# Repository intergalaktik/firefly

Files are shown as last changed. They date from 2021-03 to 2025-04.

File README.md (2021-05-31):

# Firefly

Board is designed to run custom made panels designed by Novena.

Designed to drive LED strip WS28121/WS28121

Depending on components and jumpers board can be sender or receiver. 

RJ45 connector is used as it is cheap.

UTP Cables are cheap and easily available.

Sender board is connected over USB to computer.

Currently sender board is just use as USB > RS485 pass

On receiver board switches are used to set panel ID

On computer software we can assign each LED to one or more groups and change group color with just one message.

Currently this board is using custom designed RS485 protocol.

Simple example of using LED group

https://www.youtube.com/watch?v=NDzNr1LaLNI

Example with more features implemented

https://youtu.be/98tDE7uqz9s

Testing blender render 

https://www.youtube.com/watch?v=SnCAtjjVjGQ

Parts of schematics are from:

https://github.com/TimGremalm/LightBoxNano

PCBart blender style

https://github.com/pcbarts/stylized-blender-setup

40 pcs. batch for museum installation

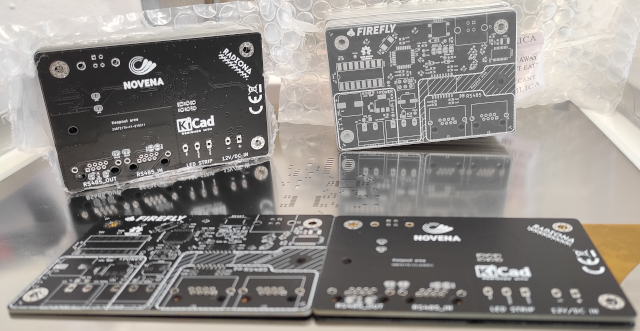
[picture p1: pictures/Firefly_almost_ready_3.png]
Stencil


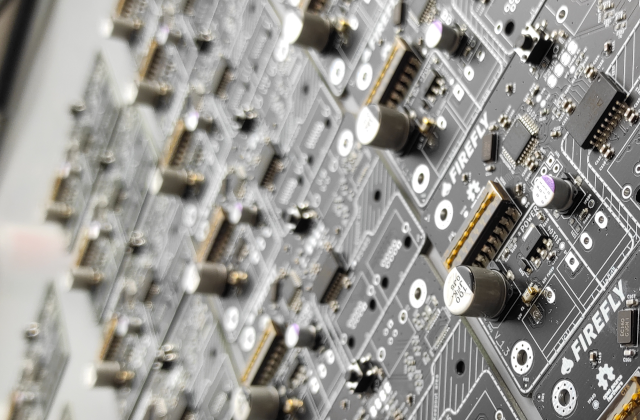
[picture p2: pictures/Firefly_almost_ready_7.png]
Half


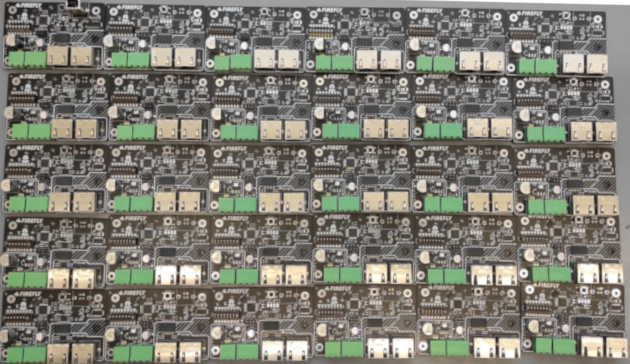
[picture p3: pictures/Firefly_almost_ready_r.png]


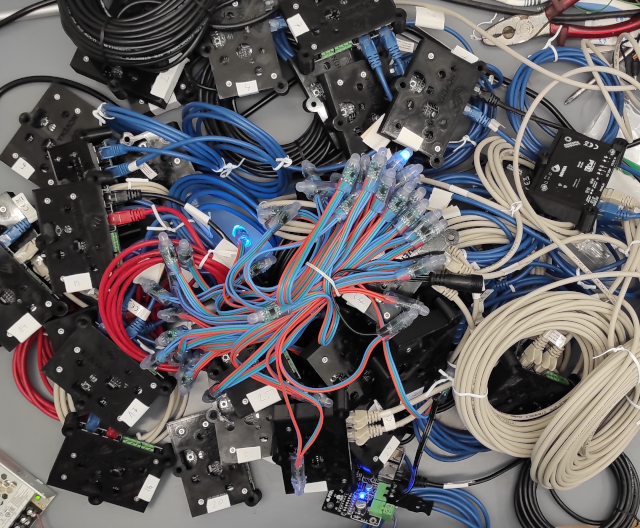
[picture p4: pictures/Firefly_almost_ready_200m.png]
Done


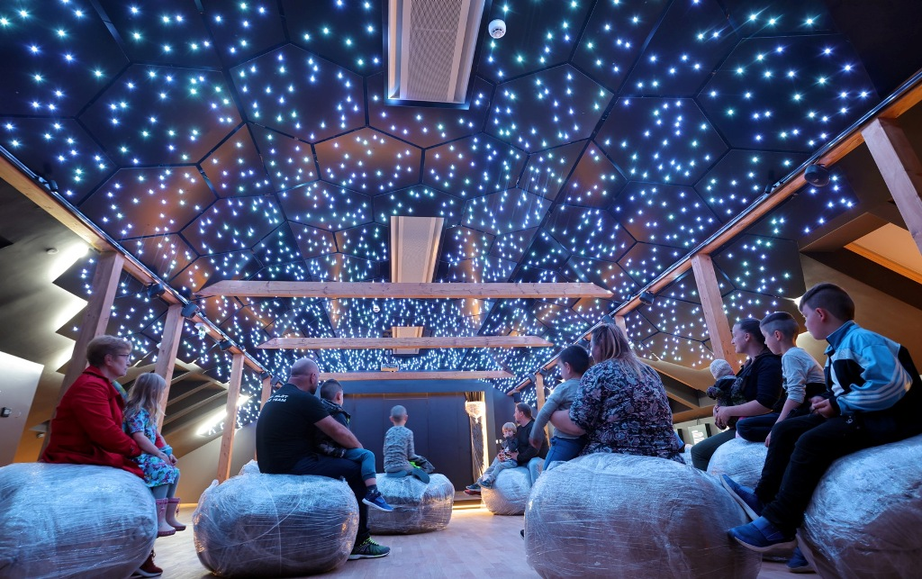
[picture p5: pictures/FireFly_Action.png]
Action


DMX test

https://www.youtube.com/watch?v=Ih8ujr5BlC8

https://www.youtube.com/watch?v=qBxfGmqJY24

https://www.youtube.com/watch?v=aGFyOSpUzw4

https://www.youtube.com/watch?v=s4EHGpA8z-Q&t=11s

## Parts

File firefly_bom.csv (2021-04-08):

References | Qty | Description | Manufacturer | MPN | Manufacturer | MPN | Manufacturer | MPN | Digikey | Mouser | RS | Newark | Farnell
Cvin1 | 1 | 100uF 50V 27m? CP_Elec_10x10 | Cornell Dubilier | AFK107M63G24T-F |  |  |  |  | 338-2146-6-ND | 5985AFK63V100F |  |  | 2131903
C101 | 1 | 100uF/16V CP_Elec_6.3x5.3 | Panasonic | 16SVPT100M |  |  |  |  | 10-16SVPT100MDKR-ND | 66716SVPT100M | 2018078 |  | 3266925
C102, C103, C108, C113, C114, C117, C118, C119, C120, C121, C122, C123, C124, C201, C205, C206 | 16 | 100n C_0603_1608Metric | Würth Elektronik | 885012206046 |  |  |  |  | 732-7965-6-ND | 710885012206046 | 8392811 |  | 2495170
C104, C105, C111, C112, C115, C116 | 6 | 10n C_0603_1608Metric | Würth Elektronik | 885012206040 |  |  |  |  | 732-7959-6-ND | 710885012206040 | 8392798 |  | 2534021
C106, C107 | 2 | 22pF C_0603_1608Metric | Würth Elektronik | 885012006019 |  |  |  |  | 732-7762-6-ND | 710885012006019 | 1813967 |  | 2533830
C109, C110 | 2 | 1uF C_0603_1608Metric | KEMET | C0603C105K8PAC |  |  |  |  |  | 80C0603C105K8PAC
C203, C204 | 2 | 47pF C_0603_1608Metric | Würth Elektronik | 885012006021 |  |  |  |  | 732-7764-1-ND | 710885012006021 | 1813913 |  | 2812096
C202 | 1 | 4.7uF C_1210_3225Metric | Würth Elektronik | 885012107013 |  |  |  |  | 732-7623-1-ND | 710885012107013 | 1813918 |  | 2533952
R1, R2, R104, R106 | 4 | 300 R_0603_1608Metric | Yageo | RC0603JR-07300RL |  |  |  |  | 311-300GRCT-ND | 603RC0603JR07300RL |  |  | 1799420
R102, Radd1 | 2 | 1K R_0603_1608Metric | Yageo | RC0603JR-071KL |  |  |  |  | 311-1.0KGRCT-ND | 603RC0603JR071KL |  |  | 1799376
R202, R203 | 2 | 27R R_0603_1608Metric | Yageo | RC0603FR-0727RL |  |  |  |  | 311-27.0HRCT-ND | 603RC0603FR0727RL |  |  | 2693669
R204, R205 | 2 | 270R R_0603_1608Metric | Yageo | AC0603FR-07270RL |  |  |  |  | 13-AC0603FR-07270RLDKR-ND | 603AC0603FR07270RL
R101 | 1 | 4K7 R_0603_1608Metric | rohm | SFR03EZPF4701 |  |  |  |  | 511-1822-1-ND | 755SFR03EZPF4701 |  |  | 2887235
R105 | 1 | 120R R_0603_1608Metric | Yageo | RC0603FR-07130RL |  |  |  |  | 311-130HRDKR-ND | 603RC0603FR07130RL |  |  | 3495733
R201 | 1 | 100K R_0603_1608Metric | Vishay | RCA0603100KJNEC |  |  |  |  | 541-3895-6-ND | 71RCA0603100KJNEC | 1885639 |  | 3546686
D102 | 1 | D_Schottky_Small D_SOD-123 | MCC | MBR0530-TP |  |  |  |  | MBR0530TPMSCT-ND | 833MBR0530TP |  |  | 1924376
D104, D105 | 2 | LED_5V LED_0603_1608Metric | Lite-On | LTST-C190GKT |  |  |  |  | 160-1183-1-ND | 859LTSTC190GKT | 6920975
D103 | 1 | LED_3V LED_0603_1608Metric | Lite-On | LTST-C190EKT |  |  |  |  | 160-1182-1-ND | 859LTSTC190EKT | 6920972
D201 | 1 | RX LED_0603_1608Metric | Lite-On | LTST-C190EKT |  |  |  |  | 160-1182-1-ND | 859LTSTC190EKT | 6920972
D202 | 1 | TX LED_0603_1608Metric | Lite-On | LTST-C190GKT |  |  |  |  | 160-1183-1-ND | 859LTSTC190GKT | 6920975
U103 | 1 | ADM2687E SOIC-16W_7.5x12.8mm_P1.27mm | Analog Devices | ADM2687EBRIZ |  |  |  |  | ADM2687EBRIZ-ND | 584ADM2687EBRIZ | 7968972P |  | 2008784
U104 | 1 | AMS1117 SOT-223-3_TabPin2 | STMicroelectronics | LD1117S50TR |  |  |  |  | 497-6447-1-ND | 511LD1117S50 | 6869379 |  | 1467781
Y101 | 1 | 16MHz Crystal_SMD_0603-2Pin_6.0x3.5mm | ECS International | ECS-160-18-23G-JGN-TR | ECS International | ECS-160-18-23B-JTM-TR |  |  | XC3086DKR-ND | 52016.01823GJGNT
F1 | 1 | Fuse DNP Fuse_1206_3216Metric_Pad1.42x1.75mm_HandSolder | Littelfuse | 0458010.DR |  |  |  |  | F2941DKR-ND | 5760458010.DR | 1740289 |  | 1692861
SW101 | 1 | SW_DIP_x08 DIP-16_W8.89mm_SMDSocket_LongPads | CTS Components | 219-8MST |  |  |  |  | CT2198MST-ND | 7742198MST | 1774234
SW102 | 1 | RESET SW_SPST_PTS645 | C&K Components | PTS645SL50SMTR92LFS |  |  |  |  | CKN9088DKR-ND | 611PTS645SL50SMTR92 | 1359177 |  | 2435163RL
ESD1, ESD2 | 2 | PESD5V0X1UAB D_SOD-323_HandSoldering | Nexperia | PESD5V0X1UAB,115 |  |  |  |  | 1727-1324-1-ND | 771PESD5V0X1UAB115 | 7918933P |  | 2069370
Jc1 | 1 | MSTBA2 PhoenixContact_MSTBA_2,5_2-G-5,08_1x02_P5.08mm_Horizontal | Phoenix Contact | 1748167 | Phoenix Contact | 1748167 | Phoenix Contact | 1755736 | 277-1150-ND | 6511755736 | 1896199 |  | 3705262
Jadd1 | 1 | MSTBA3 PhoenixContact_MSTBA_2,5_3-G-5,08_1x03_P5.08mm_Horizontal | Phoenix Contact | 1748183 |  |  |  |  | 277-8657-ND | 6511748183
J1, J2 | 2 | RJ45_Shielded RJ45_Amphenol_RJHSE5380 | Amphenol | RJHSE-5380 |  |  |  |  | RJHSE-5380-ND | 523RJHSE5380 |  |  | 1849916
U201 | 1 | FT231XS SSOP-20_3.9x8.7mm_P0.635mm | FTDI | FT231XS-U |  |  |  |  | 768-1156-5-ND | 895FT231XSU | 8888722
J3 | 1 | USB_B USB_B_TE_5787834_Vertical | TE Connectivity | 5787834-1 |  |  |  |  | 5787834-1-ND | 57157878341 | 5298224 |  | 1076666
J101 | 1 | Conn_02x03_Counter_Clockwise PinHeader_2x03_P2.54mm_Vertical
CONN1_EXT | 1 | 2P 5.08mm PLUG | TE Connectivity | 282807-2 |  |  |  |  | A106364-ND | 5712828072 | 7100422 |  | 2059789
CONN2_EXT | 1 | 3P 5.08mm PLUG | TE Connectivity | 282807-3 |  |  |  |  | A106365-ND | 5712828073 | 7100429 |  | 3133861

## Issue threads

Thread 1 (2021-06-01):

Possible error for RS485 shield jumpers

yngndrw, 2021-06-01:
Hello,

I think I've spotted a mistake around JP107 / JP108, at least on the revision which has been uploaded to TraceSpace.io: (See the bottom view)
https://tracespace.io/view/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
JP107 and JP108 both seem to do the same job, but I suspect that the intention was for either:
1) JP108 to connect the RS485 shields together and JP107 to connect the RS485 shield of the input connector to ground.
2) JP108 to connect the RS485 output shield to ground and JP107 to connect the RS485 output shield to ground.

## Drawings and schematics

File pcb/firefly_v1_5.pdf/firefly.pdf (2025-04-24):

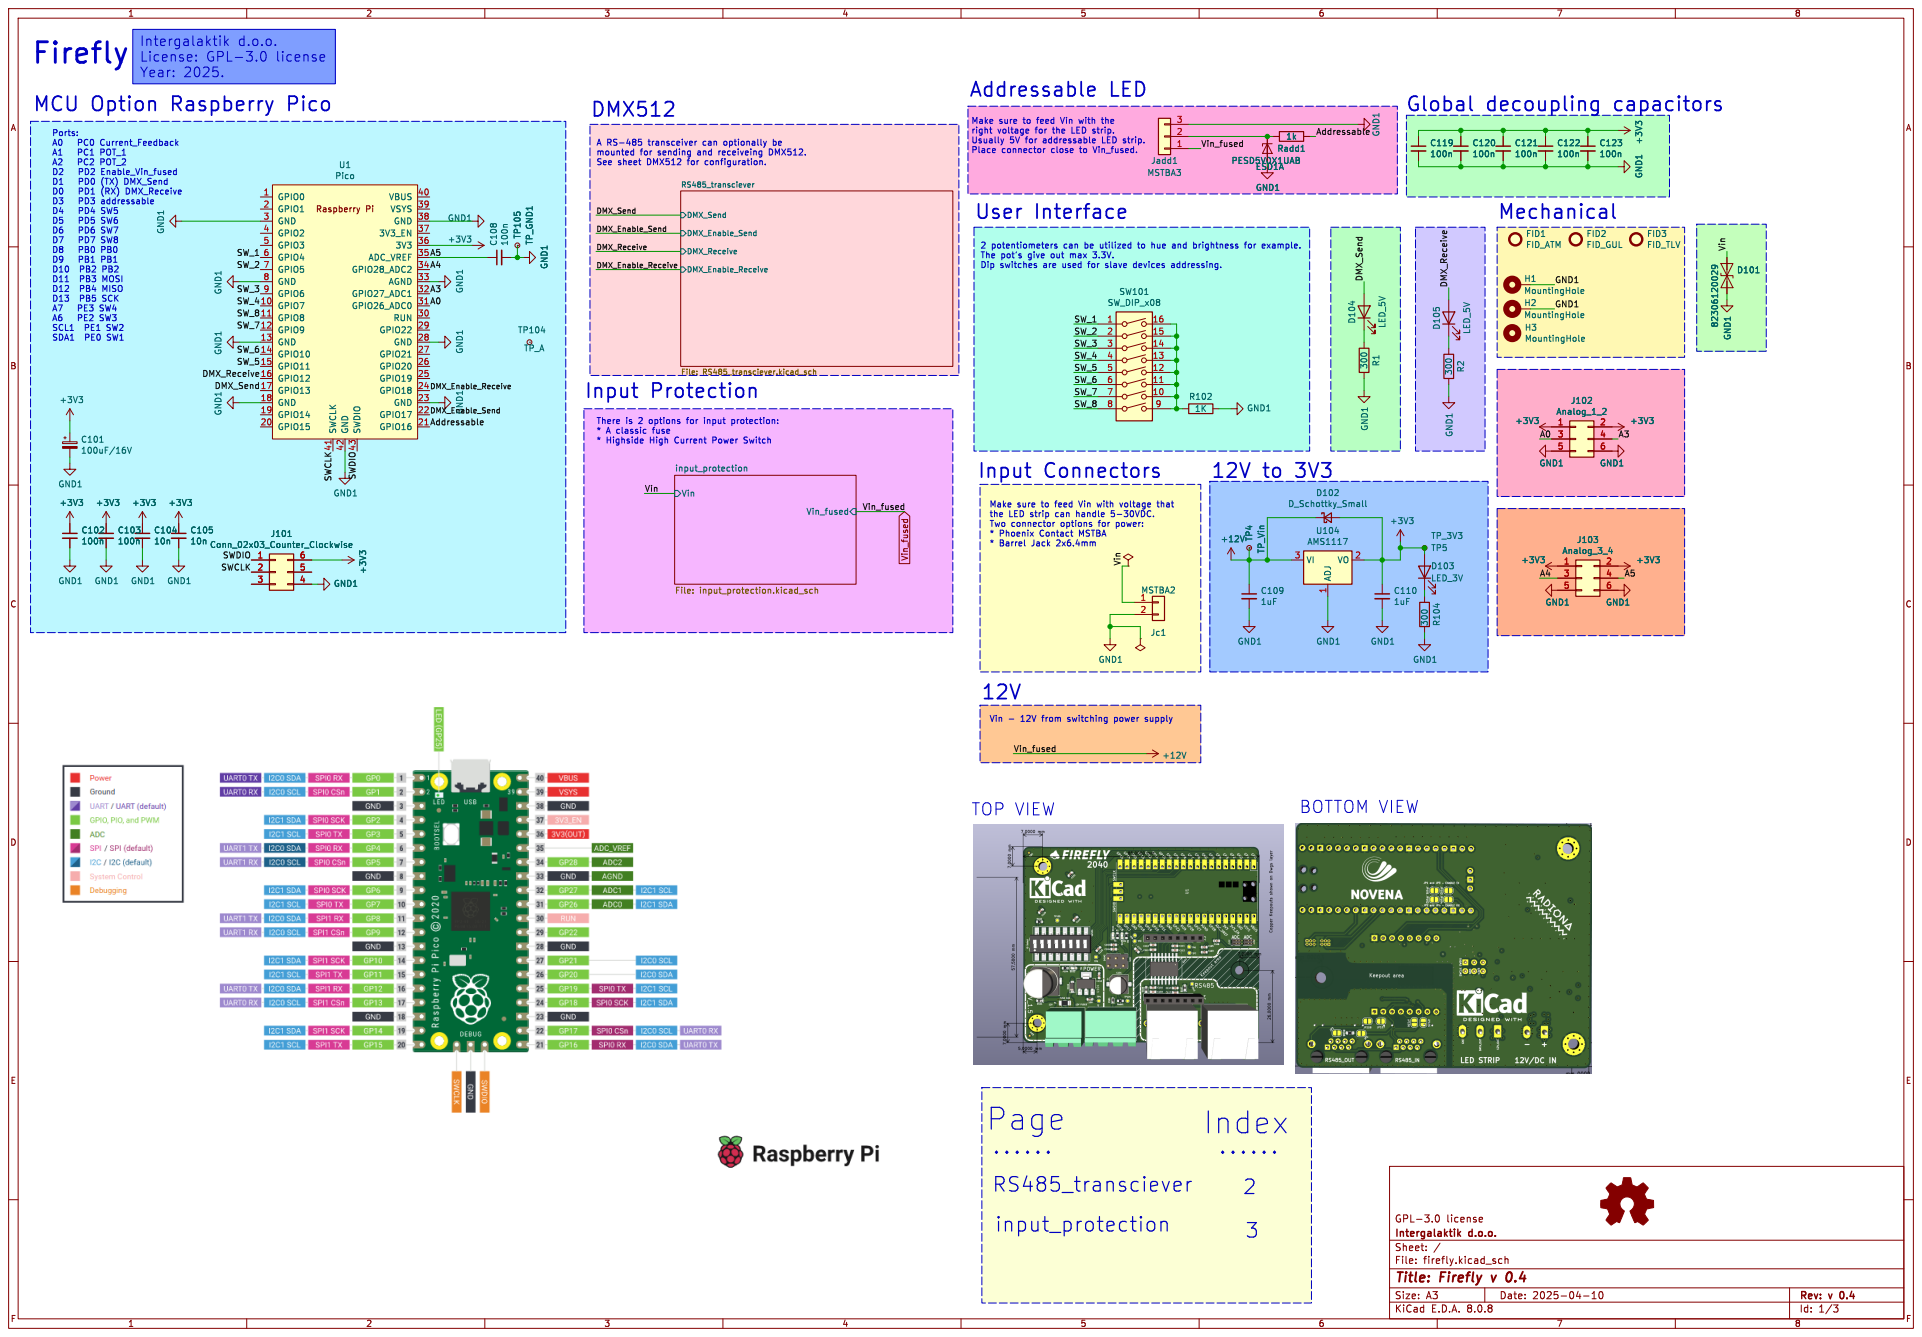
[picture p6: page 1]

MCU Option Raspberry Pico

Make sure to feed Vin with the
right voltage for the LED strip.

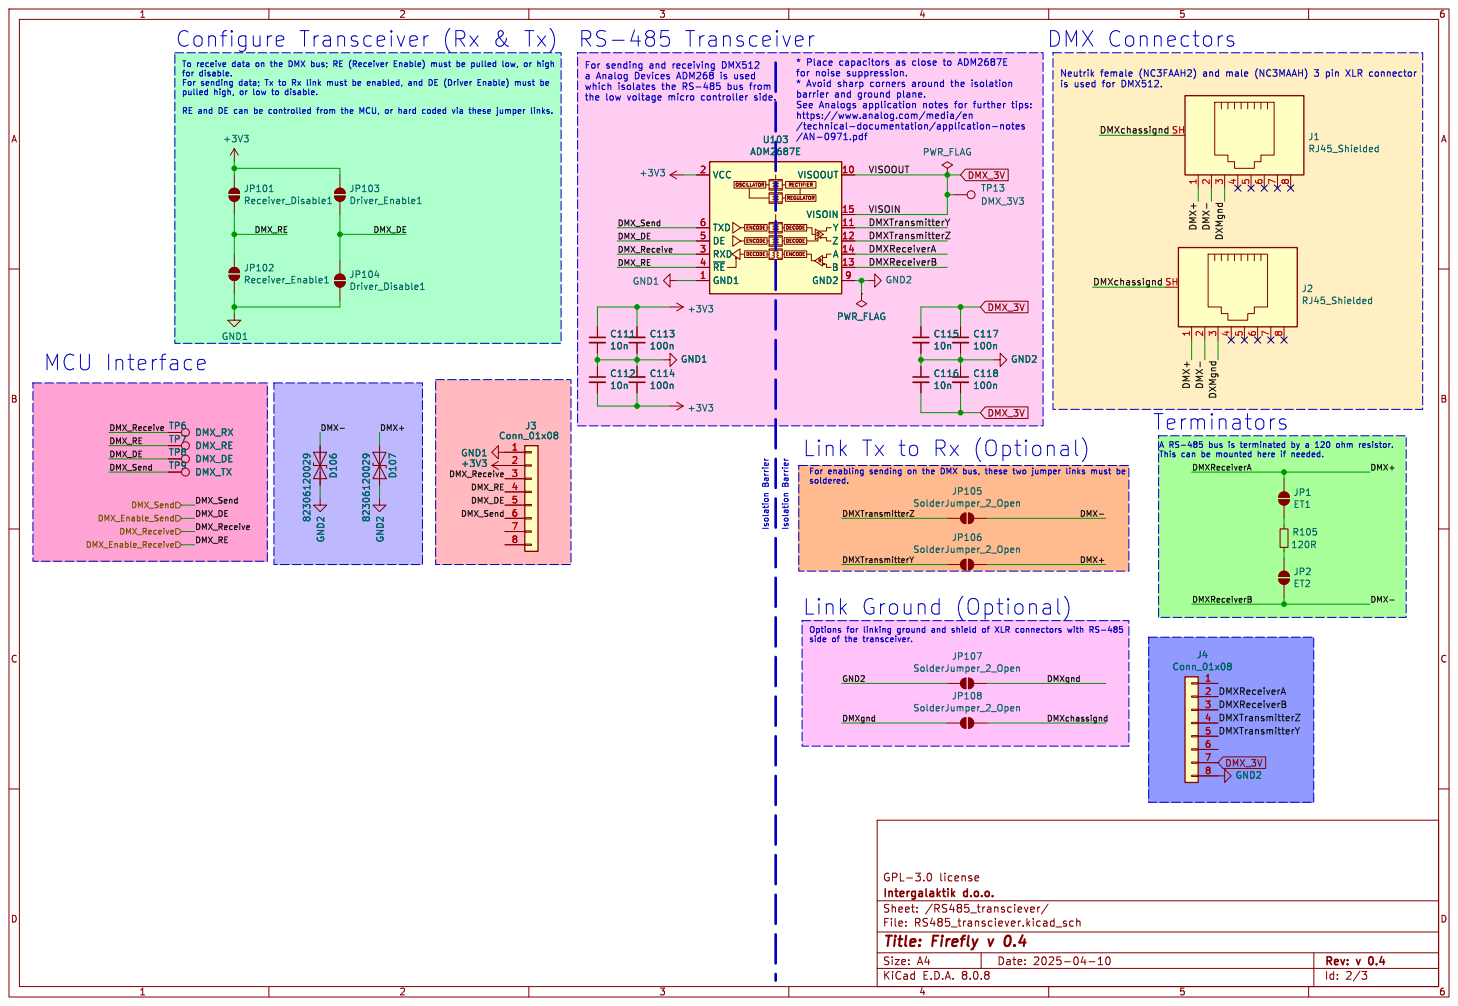
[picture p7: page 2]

for noise suppression. * Avoid sharp corners around the isolation

https://www.analog.com/media/en
/technical-documentation/application-notes
/AN-0971.pdf

Link Tx to Rx (Optional)

side of the transceiver.

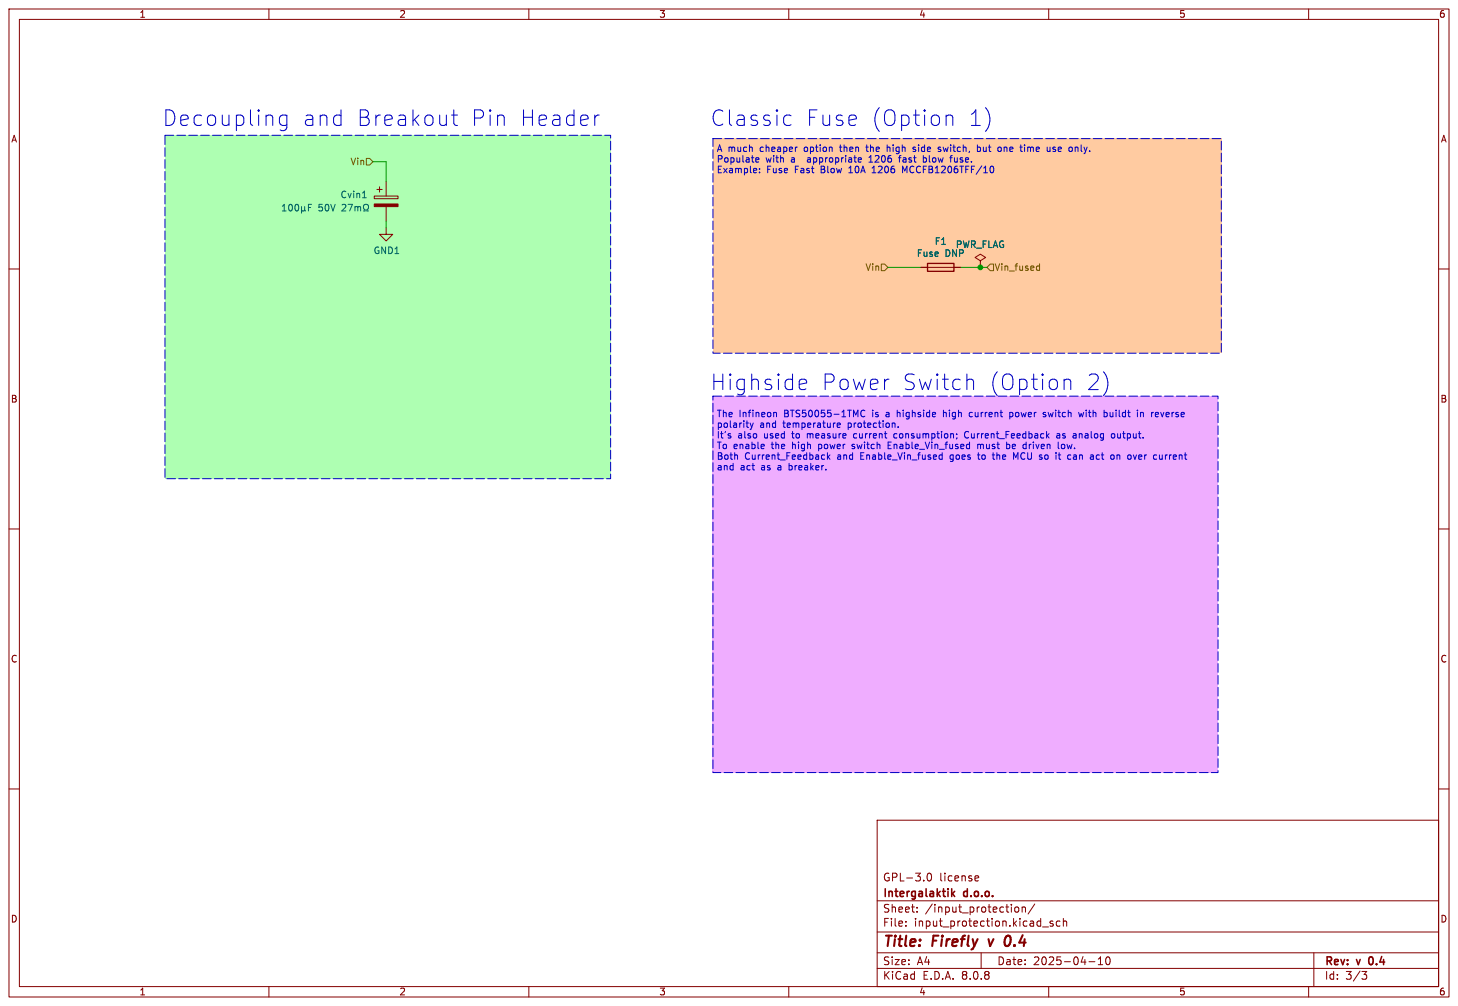
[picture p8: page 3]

A much cheaper option then the high side switch, but one time use only.

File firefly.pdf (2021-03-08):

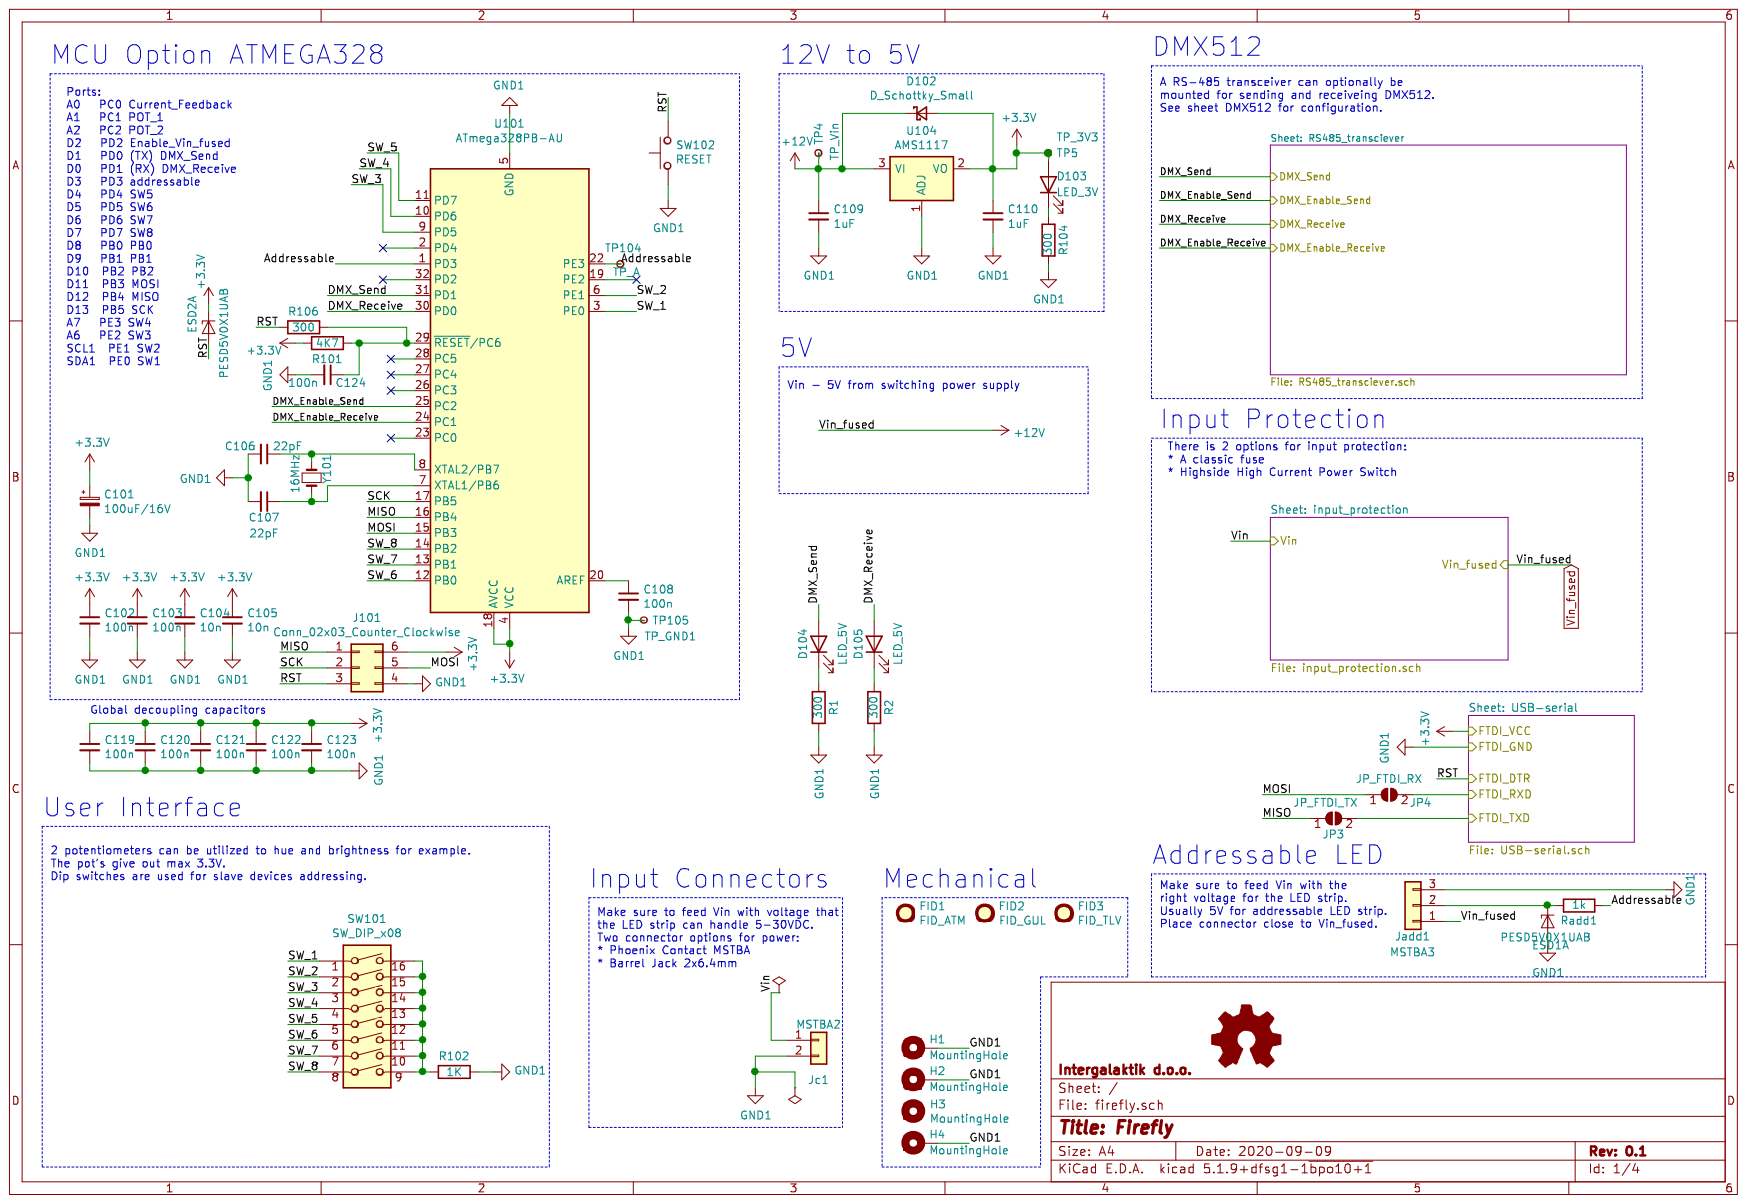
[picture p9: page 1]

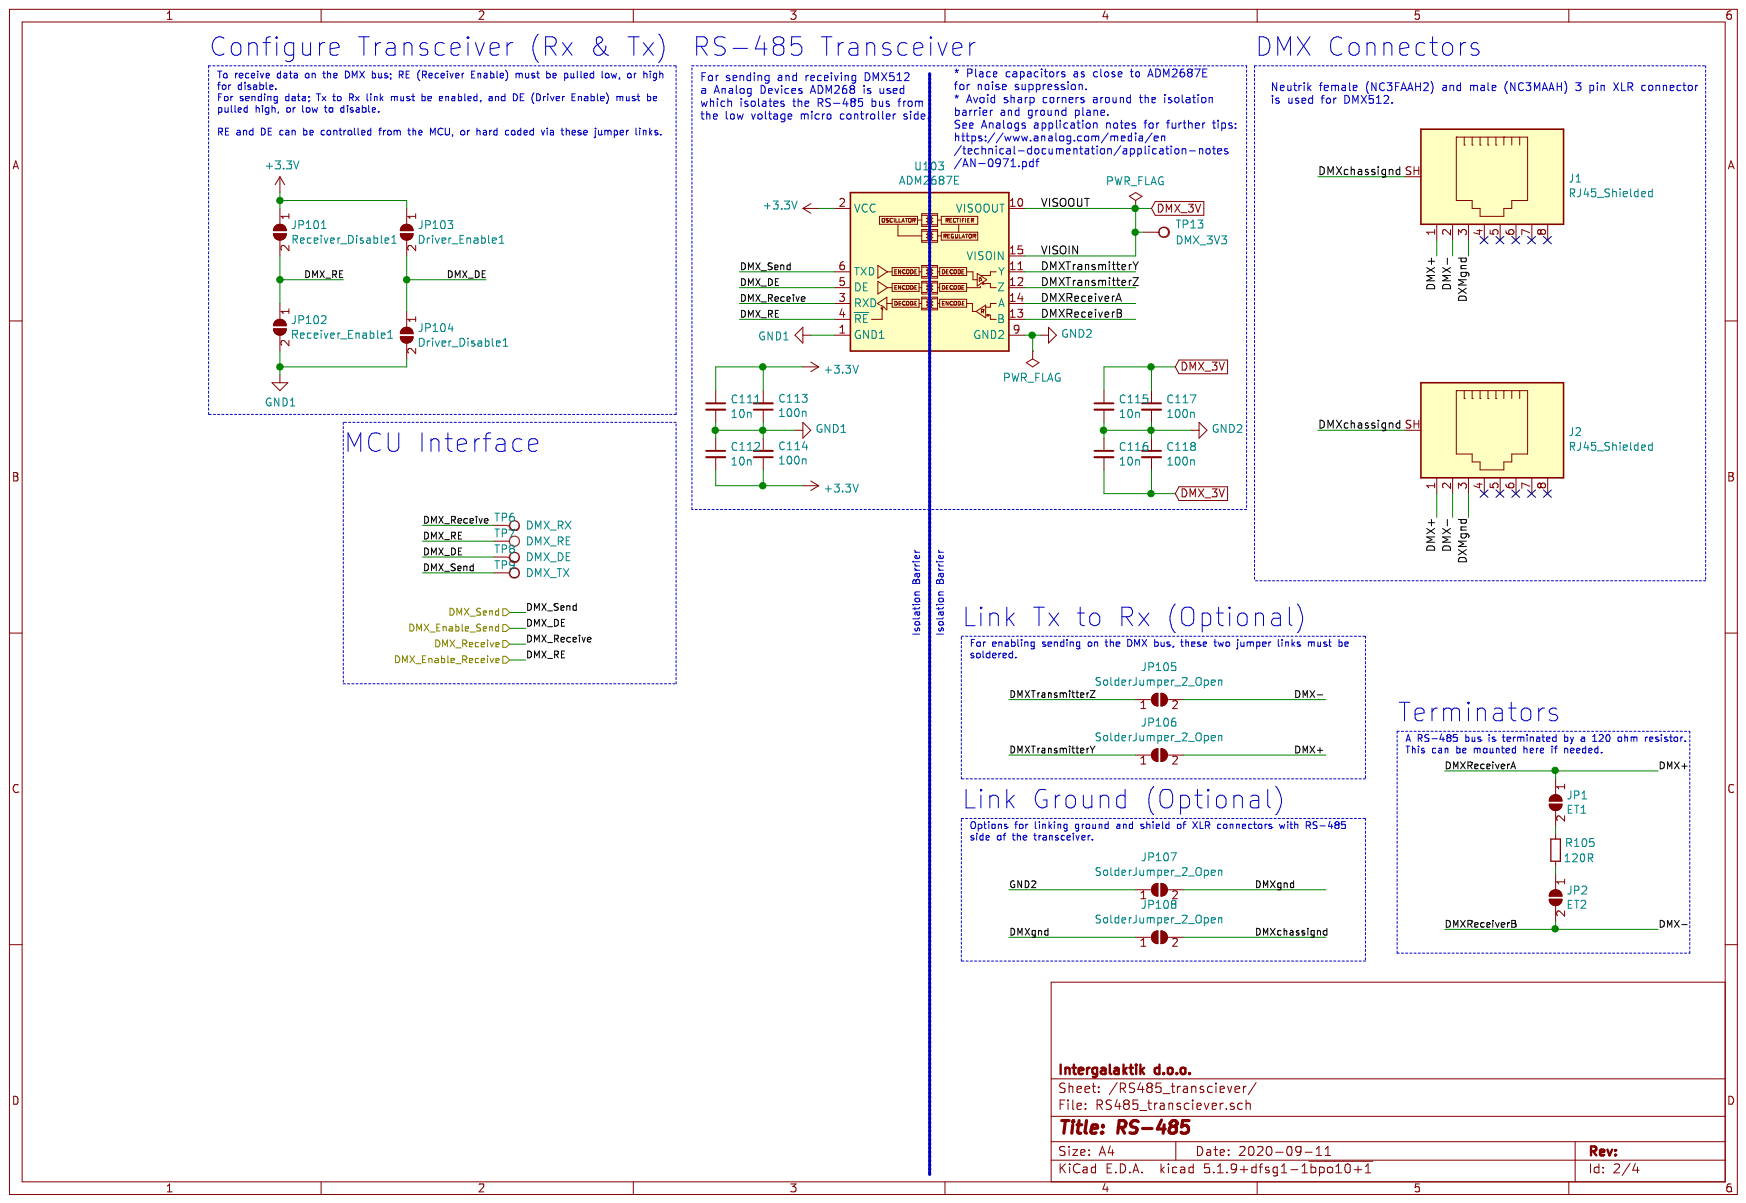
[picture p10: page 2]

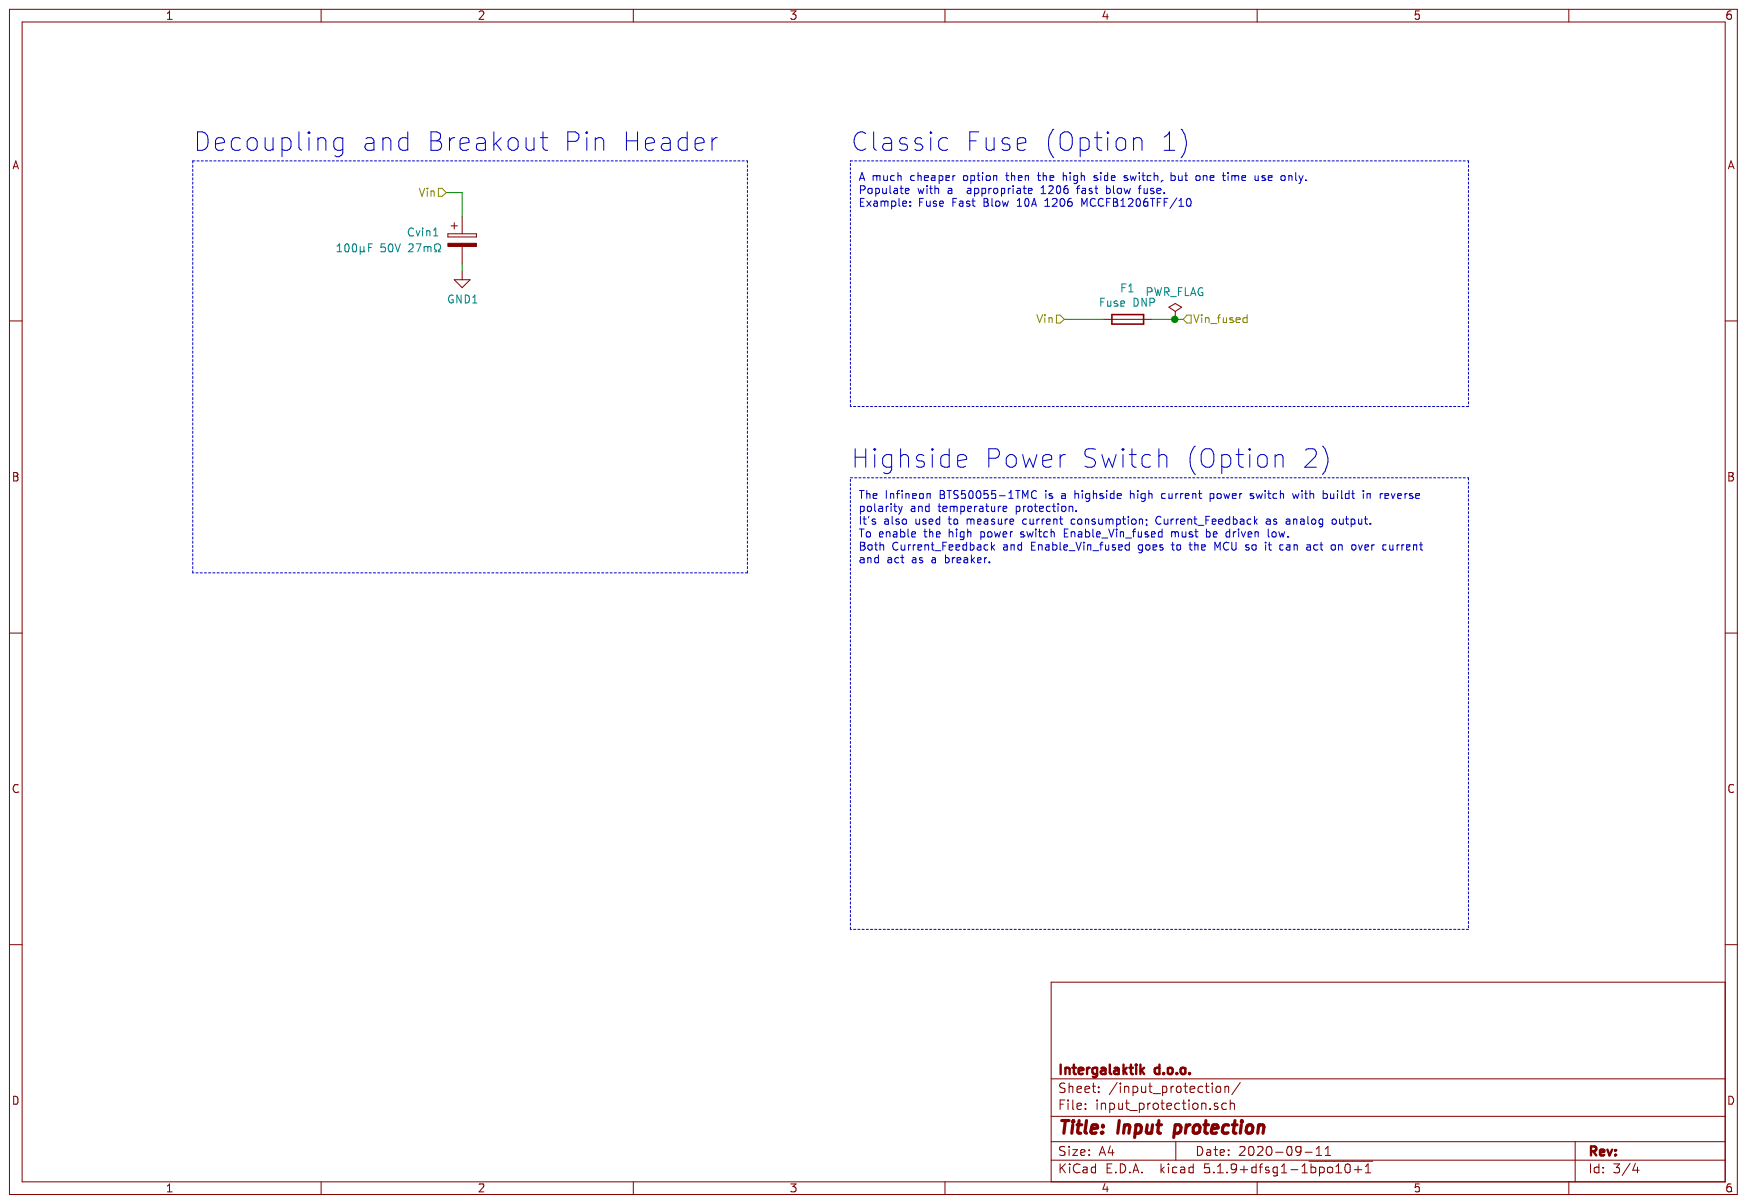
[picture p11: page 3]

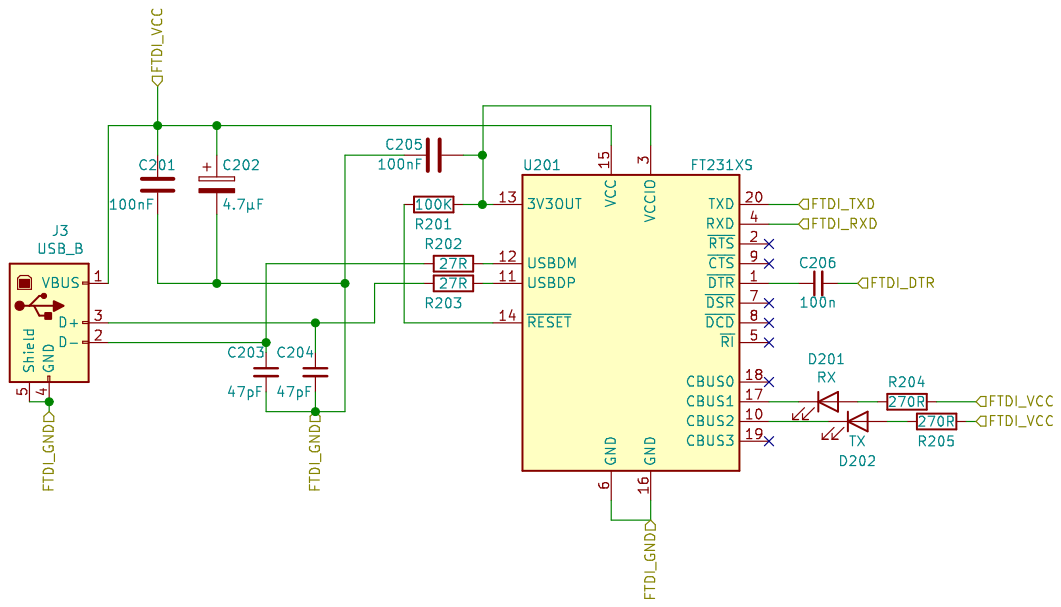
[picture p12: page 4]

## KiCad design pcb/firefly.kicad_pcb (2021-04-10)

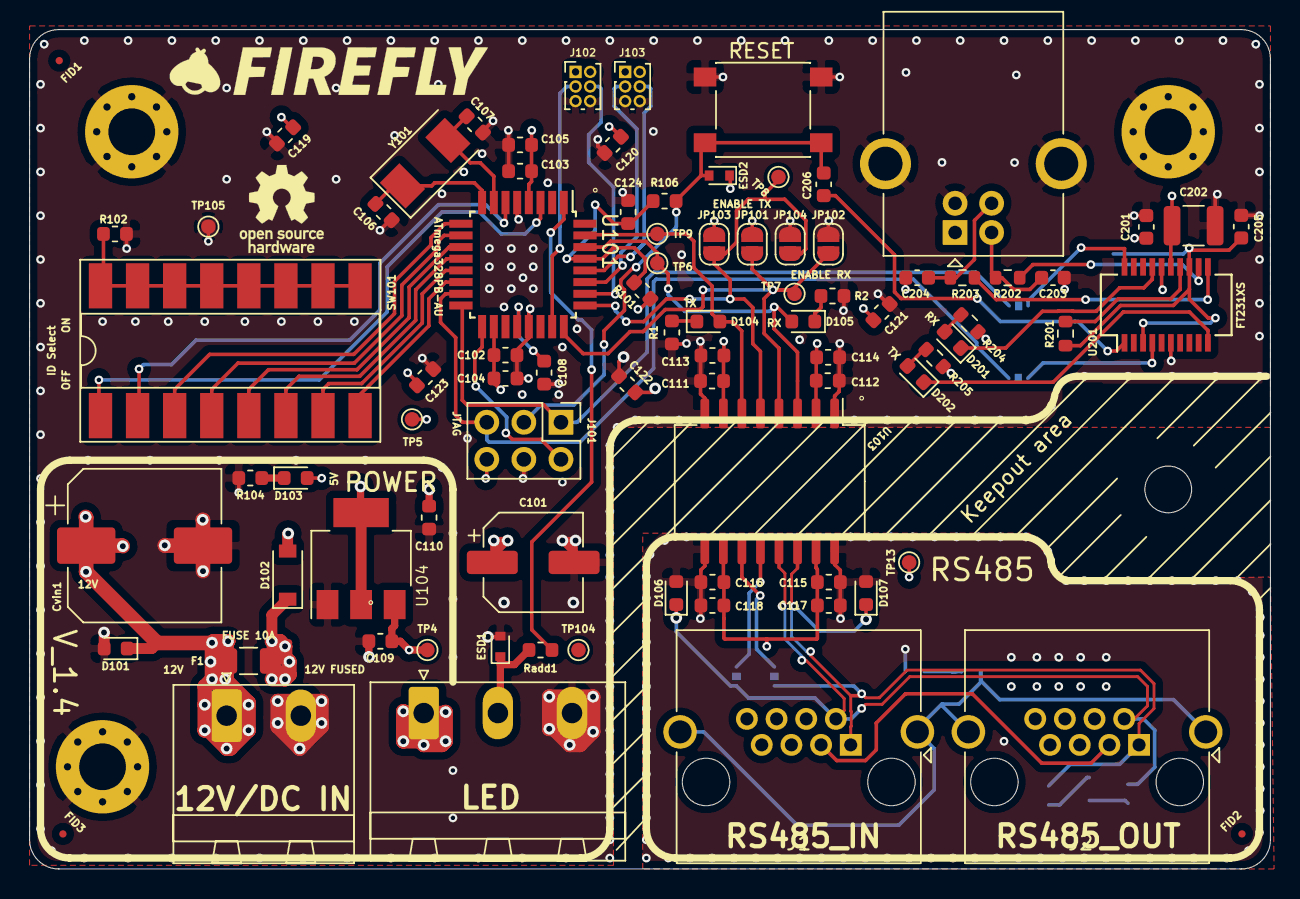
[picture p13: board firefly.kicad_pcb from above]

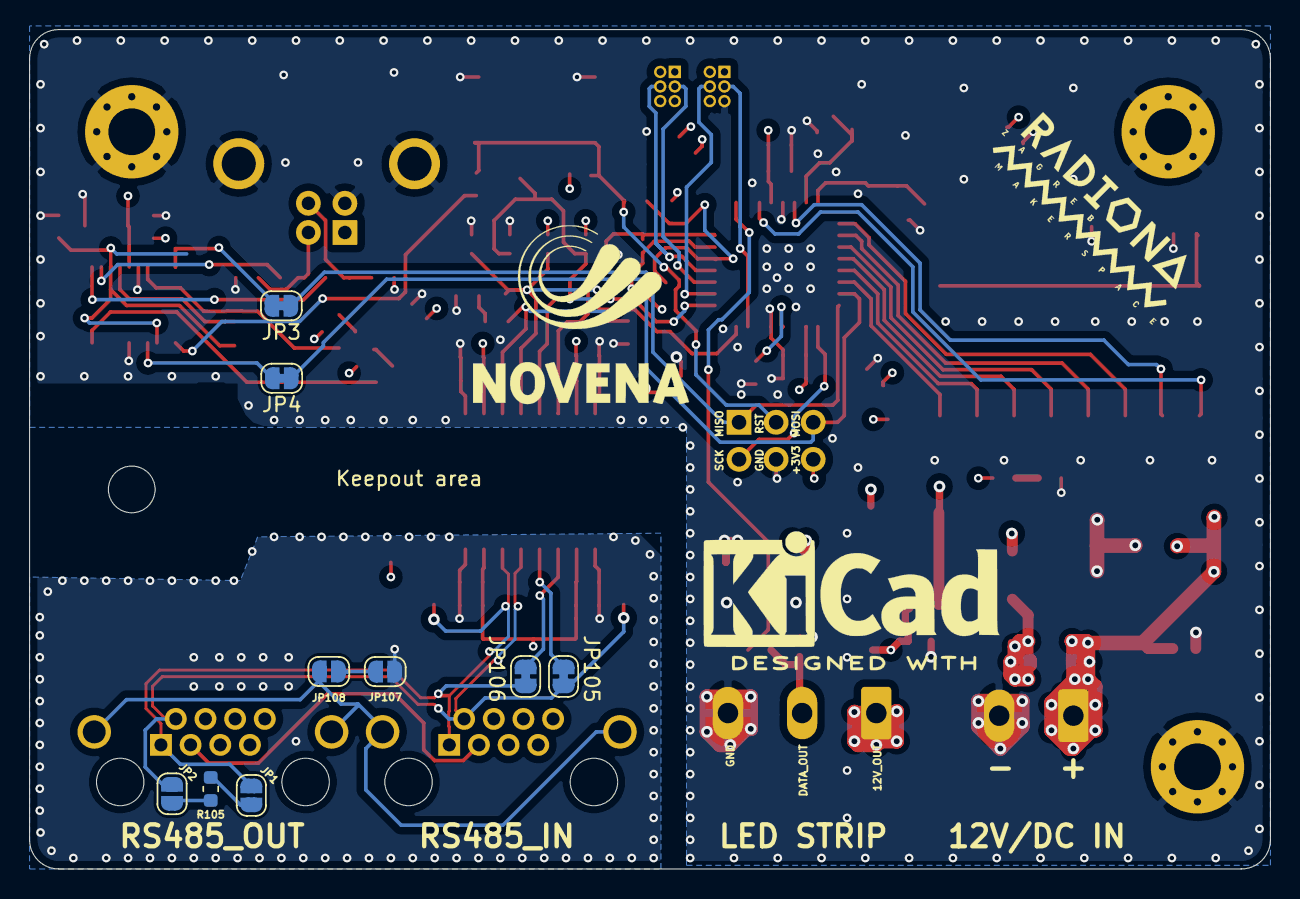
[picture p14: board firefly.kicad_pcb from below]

Board: 4 copper layers, 85.0 x 57.5 mm, 99 parts (9 on the bottom side), 58 nets.

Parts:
C101: 100uF/16V; CP_Elec_6.3x5.3
C102, C103, C108, C113, C114, C117, C118, C119, C120, C121, C122, C123, C124, C206: 100n; C_0603_1608Metric
C104, C105, C111, C112, C115, C116: 10n; C_0603_1608Metric
C106, C107: 22pF; C_0603_1608Metric
C109, C110: 1uF; C_0603_1608Metric
C201, C205: 100nF; C_0603_1608Metric
C202: 4.7µF; C_1210_3225Metric
C203, C204: 47pF; C_0603_1608Metric
Cvin1: 100µF 50V 27mΩ; CP_Elec_10x10
D101, D106, D107: 82306120029; D_0603_1608Metric
D102: D_Schottky_Small; D_SOD-123
D103: LED_3V; LED_0603_1608Metric
D104, D105: LED_5V; LED_0603_1608Metric
D201: RX; LED_0603_1608Metric
D202: TX; LED_0603_1608Metric
ESD1, ESD2: PESD5V0X1UAB; D_SOD-523
F1: Fuse DNP; Fuse_1206_3216Metric_Pad1.42x1.75mm_HandSolder
FID1: FID_ATM; Fiducial_0.5mm_Mask1mm
FID2: FID_GUL; Fiducial_0.5mm_Mask1mm
FID3: FID_TLV; Fiducial_0.5mm_Mask1mm
H1, H2, H4: MountingHole; MountingHole_3.2mm_M3_Pad_Via
H3: MountingHole; MountingHole_3.2mm_M3
J1, J2: RJ45_Shielded; RJ45_Amphenol_RJHSE5380
J3: USB_B; USB_B_OST_USB-B1HSxx_Horizontal
J101: Conn_02x03_Counter_Clockwise; PinHeader_2x03_P2.54mm_Vertical
J102: Analog_1_2; PinHeader_2x03_P1.00mm_Vertical
J103: Analog_3_4; PinHeader_2x03_P1.00mm_Vertical
JP1: ET1; SolderJumper-2_P1.3mm_Open_RoundedPad1.0x1.5mm
JP2: ET2; SolderJumper-2_P1.3mm_Open_RoundedPad1.0x1.5mm
JP3: JP_FTDI_TX; SolderJumper-2_P1.3mm_Bridged_RoundedPad1.0x1.5mm
JP4: JP_FTDI_RX; SolderJumper-2_P1.3mm_Bridged_RoundedPad1.0x1.5mm
JP101: Receiver_Disable1; SolderJumper-2_P1.3mm_Open_RoundedPad1.0x1.5mm
JP102: Receiver_Enable1; SolderJumper-2_P1.3mm_Open_RoundedPad1.0x1.5mm
JP103: Driver_Enable1; SolderJumper-2_P1.3mm_Open_RoundedPad1.0x1.5mm
JP104: Driver_Disable1; SolderJumper-2_P1.3mm_Open_RoundedPad1.0x1.5mm
JP105, JP106: SolderJumper_2_Open; SolderJumper-2_P1.3mm_Bridged_RoundedPad1.0x1.5mm
JP107, JP108: SolderJumper_2_Open; SolderJumper-2_P1.3mm_Open_RoundedPad1.0x1.5mm
Jadd1: MSTBA3; PhoenixContact_MSTBA_2,5_3-G-5,08_1x03_P5.08mm_Horizontal
Jc1: MSTBA2; PhoenixContact_MSTBA_2,5_2-G-5,08_1x02_P5.08mm_Horizontal
R1, R2, R104, R106: 300; R_0603_1608Metric
R101: 4K7; R_0603_1608Metric
R102: 1K; R_0603_1608Metric
R105: 120R; R_0603_1608Metric
R201: 100K; R_0603_1608Metric
R202, R203: 27R; R_0603_1608Metric
R204, R205: 270R; R_0603_1608Metric
Radd1: 1k; R_0603_1608Metric
SW101: SW_DIP_x08; DIP-16_W8.89mm_SMDSocket_LongPads
SW102: RESET; SW_SPST_PTS645
TP4: TP_Vin; TestPoint_Pad_D1.0mm
TP5: TP_3V3; TestPoint_Pad_D1.0mm
TP6: DMX_RX; TestPoint_Pad_D1.0mm
TP7: DMX_RE; TestPoint_Pad_D1.0mm
TP8: DMX_DE; TestPoint_Pad_D1.0mm
TP9: DMX_TX; TestPoint_Pad_D1.0mm
TP13: DMX_3V3; TestPoint_Pad_D1.0mm
TP104: TP_A; TestPoint_Pad_D1.0mm
TP105: TP_GND1; TestPoint_Pad_D1.0mm
U101: ATmega328PB-AU; TQFP-32_7x7mm_P0.8mm
U103: ADM2687E; SOIC-16W_7.5x12.8mm_P1.27mm
U104: AMS1117; SOT-223-3_TabPin2
U201: FT231XS; SSOP-20_3.9x8.7mm_P0.635mm
Y101: 16MHz; Crystal_SMD_0603-2Pin_6.0x3.5mm

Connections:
+3V3: C101.1, C102.1, C103.1, C104.1, C105.1, C110.1, C111.1, C112.2, C113.2, C114.1, C119.1, C120.1, C121.1, C122.1, C123.1, C201.1, C202.1, D102.2, D103.2, ESD2.1, J3.1, J101.6, J102.1, J102.2, J103.1, J103.2, JP101.1, JP103.1, R101.2, R204.1, R205.1, TP5.1, U101.4, U101.18, U103.2, U103.7, U104.2, U201.15
/A0: J102.3, U101.23
/A3: J102.4, U101.26
/A4: J103.3, U101.27
/A5: J103.4, U101.28
/Addressable: Radd1.2, U101.1
/DMX_Enable_Receive: JP101.2, JP102.1, TP7.1, U101.24, U103.4
/DMX_Enable_Send: JP103.2, JP104.1, TP8.1, U101.25, U103.5
/DMX_Receive: D105.2, TP6.1, U101.30, U103.3
/DMX_Send: D104.2, TP9.1, U101.31, U103.6
/MISO: J101.1, JP3.1, U101.16
/MOSI: J101.5, JP4.1, U101.15
/RS485_transciever/DMX+: D107.1, J1.1, J2.1, JP1.1, JP106.2, U103.14
/RS485_transciever/DMX-: D106.1, J1.2, J2.2, JP2.2, JP105.2, U103.13
/RS485_transciever/DMXTransmitterY: JP106.1, U103.11
/RS485_transciever/DMXTransmitterZ: JP105.1, U103.12
/RS485_transciever/DMXchassignd: J1.SH, J2.SH, JP108.2
/RS485_transciever/DMXgnd: JP107.2, JP108.1
/RS485_transciever/DXMgnd: J1.3, J2.3
/RST: C206.2, ESD2.2, J101.3, R106.2, SW102.2
/SCK: J101.2, U101.17
/SW_1: SW101.1, U101.3
/SW_2: SW101.2, U101.6
/SW_3: SW101.3, U101.9
/SW_4: SW101.4, U101.10
/SW_5: SW101.5, U101.11
/SW_6: SW101.6, U101.12
/SW_7: SW101.7, U101.13
/SW_8: SW101.8, U101.14
/USB-serial/FTDI_RXD: JP4.2, U201.4
/USB-serial/FTDI_TXD: JP3.2, U201.20
/Vin: Cvin1.1, D101.1, F1.2, Jc1.1
DMX_3V: C115.1, C116.2, C117.1, C118.2, TP13.1, U103.10, U103.15
GND1: C101.2, C102.2, C103.2, C104.2, C105.2, C106.2, C107.2, C108.2, C109.2, C110.2, C111.2, C112.1, C113.1, C114.2, C119.2, C120.2, C121.2, C122.2, C123.2, C124.2, C201.2, C202.2, C203.2, C204.2, C205.1, Cvin1.2, D101.2, ESD1.2, H1.1, H2.1, H4.1, J3.4, J3.5, J101.4, J102.5, J102.6, J103.5, J103.6, JP102.2, JP104.2, Jadd1.3, Jc1.2, R1.1, R2.1, R102.1, R104.1, SW102.1, TP105.1, U101.5, U101.21, U103.1, U103.8, U104.1, U201.6, U201.16
GND2: C115.2, C116.1, C117.2, C118.1, D106.2, D107.2, JP107.1, U103.9, U103.16
unnamed: C106.1, U101.8, Y101.1
unnamed: C107.1, U101.7, Y101.2
unnamed: C108.1, U101.20
unnamed: C124.1, R101.1, R106.1, U101.29
unnamed: C203.1, J3.2, R202.2
unnamed: C204.1, J3.3, R203.2
unnamed: C205.2, R201.1, U201.3, U201.13
unnamed: C206.1, U201.1
unnamed: D103.1, R104.2
unnamed: D104.1, R1.2
unnamed: D105.1, R2.2
unnamed: D201.1, U201.17
unnamed: D201.2, R204.2
unnamed: D202.1, U201.10
unnamed: D202.2, R205.2
unnamed: ESD1.1, Jadd1.2, Radd1.1
unnamed: JP1.2, R105.1
unnamed: JP2.1, R105.2
unnamed: R102.2, SW101.9, SW101.10, SW101.11, SW101.12, SW101.13, SW101.14, SW101.15, SW101.16
unnamed: R201.2, U201.14
unnamed: R202.1, U201.12
unnamed: R203.1, U201.11
Vin_fused: C109.1, D102.1, F1.1, Jadd1.1, TP4.1, U104.3

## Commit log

2021-02-12 Initial FireFly upload
    [RS485_transciever.sch, USB-serial.sch, firefly.kicad_pcb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]
2021-03-08 fixing broken symbols
    [RS485_transciever.sch, USB-serial.sch, firefly.sch]
2021-03-08 Adding logos, fixing text
    [firefly.kicad_pcb, firefly.sch]
2021-03-08 Before production export changes
    [firefly.kicad_pcb]
2021-03-08 Adding v_1.3 schematics
2021-03-08 Adding interactive BOM
2021-03-08 Adding files needed for kitspace
    [firefly_bom.csv]
2021-03-08 Adding gerbers
    [firefly-B_Cu.gbr, firefly-B_Mask.gbr, firefly-B_Paste.gbr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]
2021-03-24 Change oscilator and 2 pin connector
    [firefly_bom.csv]
2021-04-08 Adding protection diodes
    [RS485_transciever.sch, firefly.kicad_pcb, firefly.sch]
2021-04-09 Changing USB connector - rerouting
    [USB-serial.sch, firefly.kicad_pcb]
2021-04-10 Adding two connectors with 4 analog inputs
    [firefly.kicad_pcb, firefly.sch]
2022-10-19 Adding v1.5
    [firefly-B_Cu.gbr, firefly-B_Mask.gbr, firefly-B_Paste.gbr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]
2025-04-11 uređena schema
    [RS485_transciever.kicad_sch, firefly.kicad_sch, input_protection.kicad_sch]
2025-04-11 unesene stavke koje su falile
    [firefly.kicad_sch]

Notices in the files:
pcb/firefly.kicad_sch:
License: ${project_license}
